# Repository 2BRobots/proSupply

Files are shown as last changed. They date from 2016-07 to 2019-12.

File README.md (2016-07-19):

# proSupply

This is the ultimate power supply for your breadboard! It can give you a regulated 5v, 3.3v and 1.8v output from a USB port or charger.

What is it?

This is a power supply designed to be used in a breadboard for develop and test digital logic circuits. It has 5v, 3.3v and 1.8v outputs that makes it great for this purpose. It is powered via a micro usb connector so you can attach it your PC, phone charger or power bank. Also it has an external Vin pin, it is protected from inverse polarization, overvoltage and undervoltage. All the pins feature a overcurrent and overheating shutdown so you don't need to worry about burning your computer's USB port by a short circuit.

Why did you make it?

I make it to work with circuits in my breadboard on the go and without worry for a bad connection or overcurrent.

What makes it special?

It has a unregulated Vout pin, regulated 5v, 3.3v and 1.8v. Also it has an external Vin pin so you can power it without using the micro usb port. Regulated voltage can give up to 250ma per channel and the power supply can give up to 750ma in total before the protection circuit starts pulsing the output and the red led blinks indicating a fault condition. Also when using Vin pin the protector circuits shuts down everything is the voltage is to high in order to prevent damage, it does the same in undervoltage for prevent malfunction. This boards are manufactured by me using a DIY reflow oven, each purchase helps me to continue doing more projects and materializing ideas.

Everything is open source so you can check the schematics and eagle board files. Available in this repo. 

<iframe width="815" height="568" src="https://www.youtube.com/embed/M1XWo04UHaw" frameborder="0" allowfullscreen></iframe>

=========================================================================================================================================
DAFR Electronics invest time and resources in making this content. If you valorate our hard work please buy from us our products or donate. This work is shared under creative commons license BY-NC-SA. 

Thanks :)

=========================================================================================================================================

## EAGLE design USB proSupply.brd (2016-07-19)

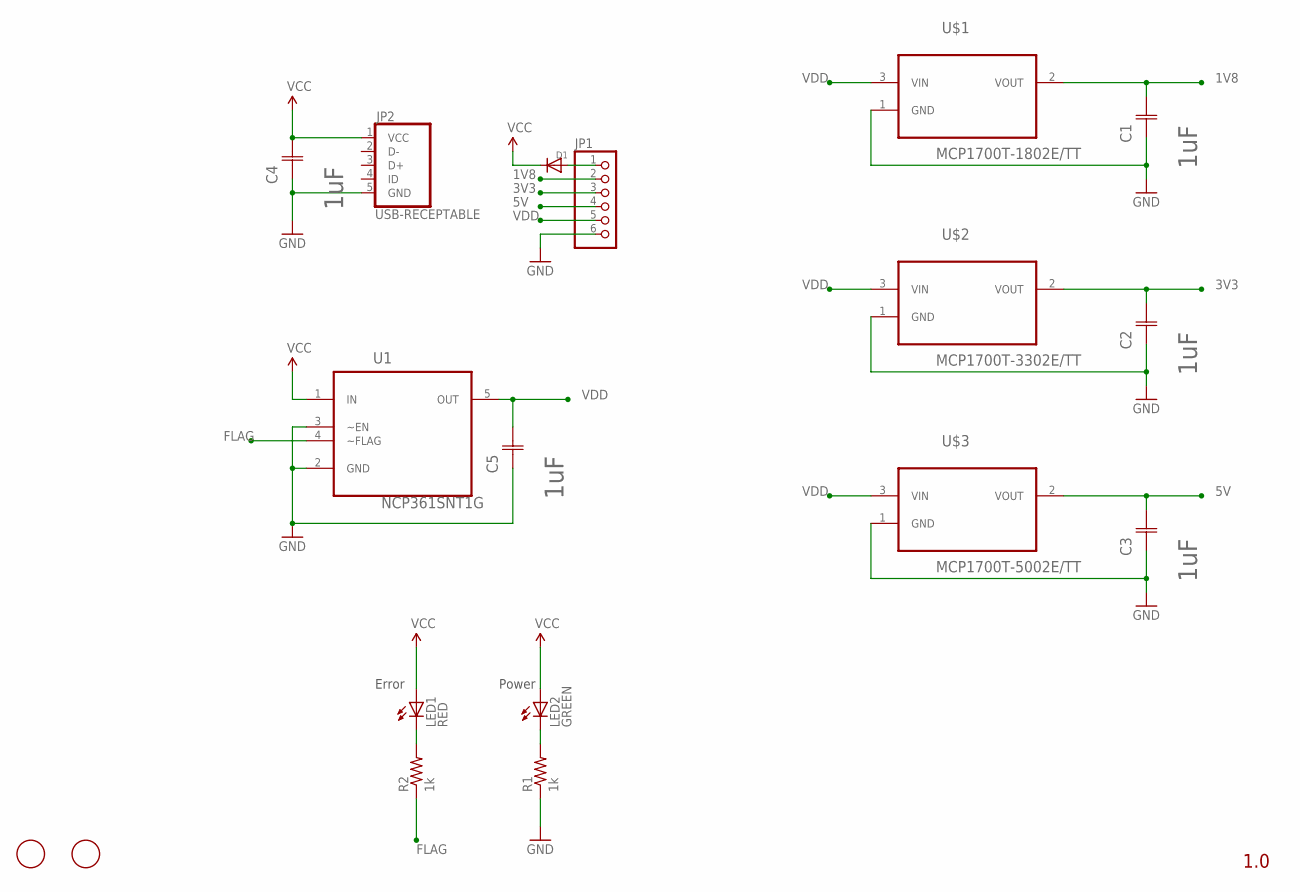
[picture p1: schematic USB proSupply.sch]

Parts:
C1, C2, C3, C4, C5: 1uF; CAPC1608X94N
D1: DIODESOD-123; SOD-123
JP1: PINHD-1X6; 1X06
JP2: USB-RECEPTABLE; FCI-10103594-0001LF
LED1: RED; CHIPLED_1206
LED2: GREEN; CHIPLED_1206
R1, R2: 1k; 0805
U1: NCP361SNT1G; SOP95P275X110-5N
U$1: MCP1700T-1802E/TT; SOT95P237X112-3N
U$2: MCP1700T-3302E/TT; SOT95P237X112-3N
U$3: MCP1700T-5002E/TT; SOT95P237X112-3N
U$5, U$6: FIDUCIAL; FIDUCIAL_1MM

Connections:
1V8: C1.2 (C2), JP1.2, U$1.2 (VOUT)
3V3: C2.2 (C2), JP1.3, U$2.2 (VOUT)
5V: C3.2 (C2), JP1.4, U$3.2 (VOUT)
FLAG: R2.1, U1.4 (~FLAG)
GND: C1.1 (C1), C2.1 (C1), C3.1 (C1), C4.1 (C1), C5.1 (C1), JP1.6, JP2.5 (GND), R1.1, U1.2 (GND), U1.3 (~EN), U$1.1 (GND), U$2.1 (GND), U$3.1 (GND)
unnamed: D1.A, JP1.1
unnamed: LED1.C, R2.2
unnamed: LED2.C, R1.2
VCC: C4.2 (C2), D1.C, JP2.1 (VCC), LED1.A, LED2.A, U1.1 (IN)
VDD: C5.2 (C2), JP1.5, U1.5 (OUT), U$1.3 (VIN), U$2.3 (VIN), U$3.3 (VIN)

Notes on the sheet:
1.0
Error
Power

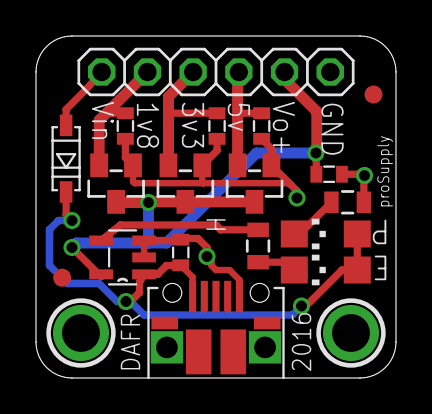
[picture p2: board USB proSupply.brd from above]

Board: 2 copper layers, 20.0 x 19.0 mm, 18 parts (0 on the bottom side), 10 nets.

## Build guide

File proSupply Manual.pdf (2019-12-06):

## proSupply – Protoboard Power Supply

## Operating Guide

Thank you very much for your support. We hope you enjoy your new breadboard power supply.

### Description:

This is a power supply designed to be used in a breadboard for development and testing of digital logic circuits. It has 5v, 3.3v and 1.8v outputs that makes it great for this purpose. It is powered via a micro USB connector, so you can attach it your PC, phone charger or power bank. Also, it has an external Vin pin that is protected from inverse polarization. All the output pins feature an overcurrent and overheating protection, so you don't need to worry about burning your computer's USB port by a short circuit. The input voltage has an overvoltage and undervoltage protection to prevent damage or malfunctioning circuits.

It has an unregulated Vout pin that can supply up to 750ma, regulated 5v, 3.3v and 1.8v. Each regulated voltage output can give up to 250ma (the 1.8v output only supplies 200ma) and the power supply can give up to 750ma in total (shared between all outputs) before the protection circuit starts pulsing the output and the red led blinks indicating a fault condition. The protection circuit shutdown the outputs if the input voltage is too high or to low and the red led remains on until the fault condition disappears.

Also, it has an external Vin pin, so you can power it without using the micro usb port. Please note that this board is designed to work with 5vdc input and inverse polarization protection only works when powering from Vin pin. You should also consider that the protection diode will affect slightly the undervoltage and undervoltage protection thresholds. Don’t power both inputs at the same time.

DO NOT SUPPLY MORE THAN 20 VDC OR THE BOARD WILL BE DAMAGED.

### Technical details:

- Overvoltage protection up to 20 volts.
- Vo+ can supply unregulated voltage up to 750ma. Shared with the regulated voltage outputs.
- 5v and 3v3 can supply up to 250ma of regulated voltage. Independent protected against overcurrent.
- 1v8 can supply up to 200ma of regulated voltage. Independent protected against overcurrent.
- Power from micro USB and Vin pin. The input voltage is 5v. Don’t power both inputs at the same time.
- Inverse polarization protection only in Vin pin. Protection diode can alter slightly the voltage thresholds.
- Low voltage threshold at around 3v in the input, outputs turned off. Red LED is ON indicating the fault.
- High voltage threshold at around 5.67v in the input, outputs turned off. Red LED is ON indicating the fault.
- Overcurrent threshold at 750ma, outputs will start pulsing. Red LED BLINKS indicating the fault.
- Green LED turn on if the board is powered.

Everything is open source, so you can check the schematics and eagle board files. We highly recommended to check the regulators and USB protector datasheets and the schematic of the board for more information. https://github.com/DAFRELECTRONICS/proSupply www.2brobots.com

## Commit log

2016-07-19 Publishing v1 of the boards
    Note: USB connector footprint must be fixed for better grip.
    [USB proSupply.brd, USB proSupply.sch]
2019-12-06 Update USB proSupply.sch
    [USB proSupply.sch]

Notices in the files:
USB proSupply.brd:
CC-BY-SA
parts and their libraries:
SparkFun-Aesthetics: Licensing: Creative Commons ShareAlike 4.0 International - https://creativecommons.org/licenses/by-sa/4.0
